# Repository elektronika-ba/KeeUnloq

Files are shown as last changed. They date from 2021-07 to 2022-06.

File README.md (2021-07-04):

# KeeUnloq
Tool for playing with Microchip KeeLoq technology.

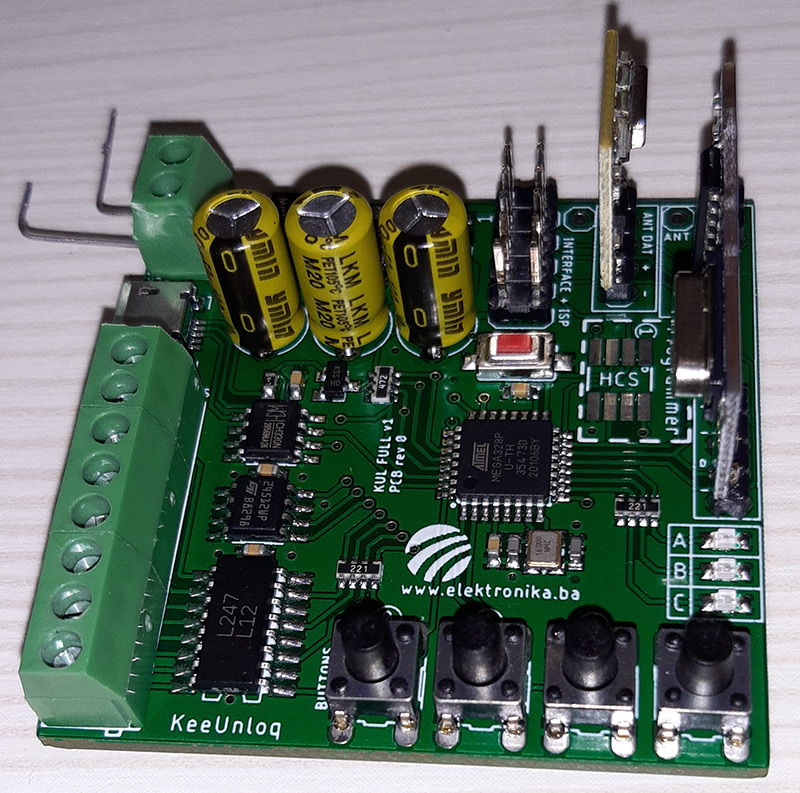
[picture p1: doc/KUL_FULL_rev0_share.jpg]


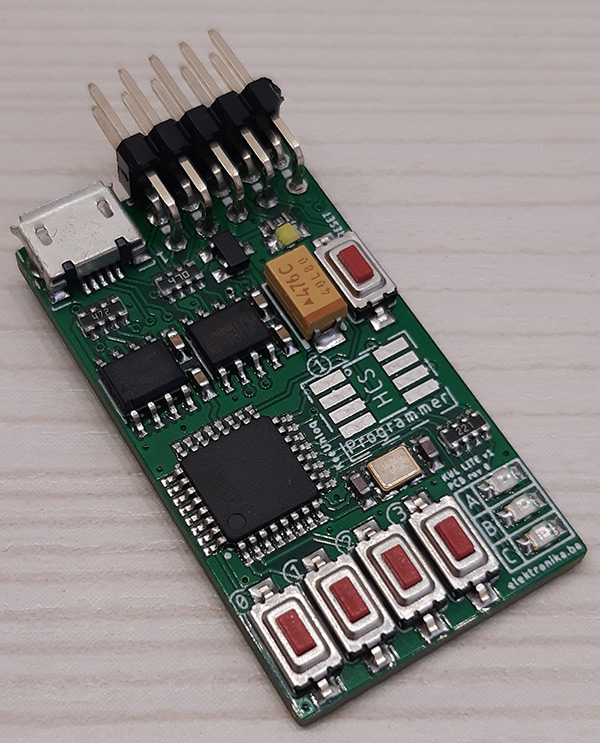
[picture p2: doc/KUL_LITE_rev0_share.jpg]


# Status
Under development. More information will be available on www.elektronika.ba

Read the doc @ [Documentation](doc/KeeUnloq_fw1.0.docx)

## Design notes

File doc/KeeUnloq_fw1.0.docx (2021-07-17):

# KeeUnloq

Open-source tools for exploring Microchip KeeLoq keyless remote systems (the old ones).

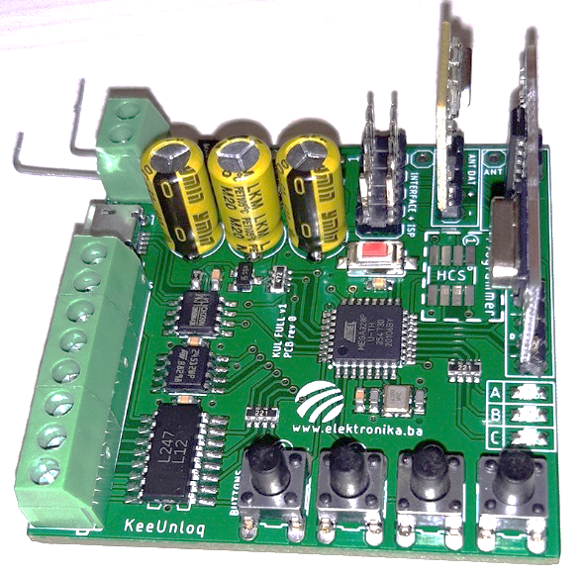
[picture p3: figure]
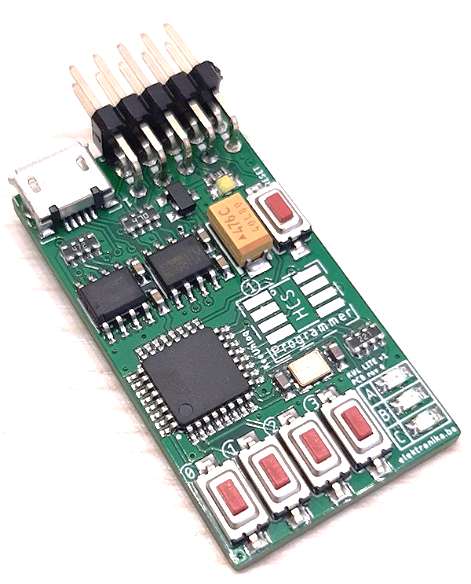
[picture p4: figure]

KUL FULL v1 PCB rev 0 | KUL LITE v1 PCB rev 0

## Features

Device comes in two PCB variants: KUL FULL and KUL LITE.

Note: version KUL FULL contains RF receiver and transmitter while KUL LITE does not.

- Receiver module with optocouplers (only with PCB „KUL FULL“)
- Upgrading third-party insecure systems that use fixed-code HCS101 with rolling-code HCS versions (HCS200, HCS300, ...)
- Emulating HCS transmitter (only with PCB „KUL FULL“ or with external RF ASK transmitter)
- KeeLoq HCS series programmer tool (requires PC software)
- PC software for programming HCS series chips, upload & download of collected transmitter data and more
- Firmware upgrade via USB
- Powered externally or by USB
  - 5V DC or 9-24 AC/DC (PCB „KUL FULL“)
  - 5V DC (PCB „KUL LITE“)
- Open source

## Modes of operation/options

Devices with FW v1 supports four selectable options during its operation:

1. Option 1: Receiver module with memory of up to 1000 remote transmitters
2. Option 2: MITM upgrader for upgrading third-party systems (insecure garage door openers)
3. Option 3: Data collector with memory of up to 200 remote transmitters and 500 transmissions
4. Option 4: Transmitter emulator

### Setting options

Each option can be enabled/disabled by holding down button S0 and resetting the device (via reset button or by supplying power). In this state LED A will remain ON and device will report status of all options (enabled/disabled). Option can be selected with button S1 and switching its state is done with button S2. When option is selected with button S1 its current state (enabled/disabled) is shown on LED C (blinking 1 time = disabled, blinking 2 times = enabled).

Example 1: LED B blinks 2 times, and LED C blinks 2 times: Option 2 is enabled.

Example 2: LED B blinks 3 times, and LED C blinks 1 time: Option 3 is disabled.

If buttons S1 or S2 are not pressed within 15 seconds, the device will exit option-change procedure and start with operation with currently enabled options. If you need exit the procedure before the timeout, press button S3.

Upon startup the device will always report the state of all options on LED A.

Example: If options 1 and 3 are enabled, LED A will blink as: 1 time – pause – 3 times.

Note: When Option 4 is enabled, it will automatically disable all other options.

### Option 1: Receiver module

Receiver module is used as a stand-alone receiver, which is capable of learning up to 1000 KeeLoq remote transmitters. It has 4 digital optocoupler outputs S0-S3 (only PCB „KUL FULL“) which are usually connected to garage door and parking barrier motor controllers. It is also capable of learning fixed-code and rolling-code HCS series that require programming before usage.

Please refer to Table 1 in Programming remote transmitters and encoder ICs.

### Option 2: MITM upgrader

Man-in-the-middle upgrader is a mode of operation where the goal is to upgrade a fixed-code insecure third-party system with a rolling-code transmitter. Rolling-code HCS series are pin-compatible with HCS101 fixed code encoder so modifying existing insecure transmitters should be an easy task by simply replacing ICs and programming new HCS with KeeUnloq device.

In order for this mode of operation to be successful, a third-party system must be modified as shown in the schematic diagram below.

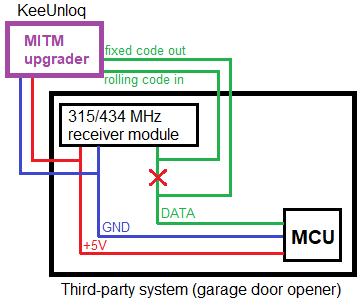
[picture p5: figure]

The data line of the third-party system must be intercepted so that any data received by the RF receiver is passed into the KeeUnloq device, and special data line from the KeeUnloq device passed into the third-party system.

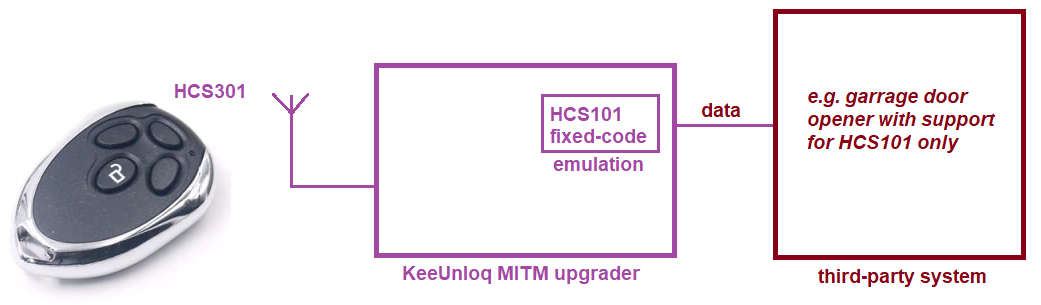
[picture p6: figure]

This means that KeeUnloq device must learn:

1. Fixed-code HCS101 remote control (only one HCS101) that third-party system already recognizes and works with
2. Rolling-code transmitter that will be learned by the KeeUnloq device (as many as required)

After installing the KeeUnloq MITM device into the third-party system, regular programming must take place with one exception: ~~The remote transmitter that has been last learned by the~~ ~~KeeUnloq~~ ~~device will be passed/proxied into the third-party system upon reception of a valid learned rolling-code remote transmitter.~~

Please refer to Table 1 in Programming remote transmitters and encoder ICs.

### Option 3: Data collector

This option is intended for collecting KeeLoq data from the air in order to evaluate and study the security of third-party systems for vulnerabilities.

When device is in this state it will listen and collect transmissions into internal EEPROM memory. All data can be downloaded to PC software via USB connection for later analysis.

Pressing button S0 on device will indicate how many new remote devices have been collected until device has started/booted.

Pressing button S1 on device will indicate how many devices are collected in entire EEPROM memory.

Number of collected transmitters is reported by blinking the LEDs:

- LED A – hundreds
- LED B – tens
- LED C – ones

Example 1: LED A blinks 2 times, LED B does not blink, LED C blinks 7 times; the resulting number is 207.

Example 2: LED A blinks 11 times, LED B blinks 2 times, LED C does not blink; the resulting number is 1120.

### Option 4: Transmitter emulator

In this mode it is possible to emulate any of the HCS series encoders. It is required to previously program the “transmitter identity” via USB connection and PC software:

1. Type of encoder (HCS*)
2. Serial number
3. Encryption key (if applicable)
4. Counter value

Once device is in this mode, all four buttons are used to transmit the data (S0 – S3).

## Programming remote transmitters and encoder ICs

Programming is done by accessing buttons S0-S3 or via PC software when device is connected via USB.

Program & learn

To learn rolling-code encoder into the device memory, place programming clips on the HCS IC or place it on the PCB programming slot and hold it down firmly. Hold button S0 to enter programming mode and LED B will turn ON. Within 20 seconds press one of the buttons:

- S0 – program&enroll 66 bit encoder (HCS200)
- S1 – program&enroll 66 bit encoder (HCS201)
- S2 – program&enroll 66 bit encoder (HCS300, HCS301, HCS320)
- S3 – program&enroll 67 bit encoder (HCS360, HCS361)

Each HCS encoder IC will be programmed with a random serial number, random encryption key, random discrimination value (except HCS360 & HCS361 which mirror the serial number value) and random counter value (but kept in the range of 0 – 255). This means that encoder ICs programmed using KeeUnloq device cannot be later enrolled using “Learn from RF” function in case KeeUnloq memory is later deleted - encoder ICs will need to be re-programmed. If it is required that all encoder ICs share the same encryption key, then use the PC tool to program them individually to the master encryption key of your choice. This master key resides in KeeUnloq memory.

The device will remain in this state for 20 seconds after the last transmitter has been programmed and will exit automatically.

Learn from RF

To learn a remote transmitter into the device memory from RF, hold button S1 to enter programming mode and LED B will turn ON. Within 10 seconds press any button on a remote control and LED B will start blinking. Press again the same button on remote control within 5 seconds.

If learning process was successful LED C will blink:

- 2 times if remote has been recognized using pre-configured master key as a rolling-code encoder
- 5 times if remote has been recognized as a fixed-code encoder or if using the pre-configured master key did not decrypt the data successfully so the encoder received will be treated as fixed-code type

If programming was not successful LED A will blink:

- 2 times if remote is already programmed into the memory (you can try first deleting it and then learning it again)
- 3 times if device is in Mode 2 and there is already HCS101 emulating encoder enrolled
- 5 times if remote failed to program because second reception did not match the first reception (you can simply try again)
- 10 times if this remote is not supported by current firmware

The device will remain in this state for 10 seconds after the last transmitter has been received and will exit automatically.

This process will enroll a fixed-code remote transmitter HCS101 any time, or a rolling-code transmitter with the encryption key that has been earlier loaded into the KeeUnloq device via USB and PC configuration tool. This also means that every remote transmitter must have this exact encryption key already programmed into them. It will also enroll a rolling-code transmitter even if the encryption key does not match, however it will be treated as a fixed-code transmitter where only serial number is used just like with HCS101.
Remove transmitter from memory (one-by-one) | In order to delete a specific remote transmitter from the memory, press and hold button S2. LED B will start blinking. Press any button on a remote transmitter that needs to be deleted from the memory. LED A will turn ON to indicate the successful reception of the code. When remote transmitter has been deleted from the memory, LED C will blink 2 times to confirm deletion, or LED A will blink 2 times to confirm that remote has not been found in memory. The device will remain in this state for 10 seconds after the last transmitter has been received and will exit automatically.
Clear all memory | In order to clear all memory from the device, press and hold button S3 until LED A starts blinking. Now within 5 seconds press and hold button S2 until LEDs B&C turn on. Release all buttons and wait until all LEDs finally turn off – the memory is clear. When options are enabled: - Option 1: will delete learned/enrolled encoders that can operate the device - Option 2: will delete learned/enrolled MITM emulating encoder - Option 3: will delete entire grabbed/log table - Option 4: will delete nothing

Table 1: programming remote transmitters and encoder ICs

## Appendix

Example of installation of MITM Upgrader into a garage door opener that supports HCS101. Before continuing make sure that garage door opener is programmed and controllable by the working remote transmitter that has HCS101 encoder inside.

Step 1: access the garage door openers RF receiver

Step 2: cut the data line and pass it through the KeeUnloq device and power up the garage door opener. Now change KeeUnloq mode into the MITM Upgrader (refer to the instructions in this document on how to change the operating mode)

Step 3: perform the Program & learn procedure of the existing HCS101 remote controller into the KeeUnloq

Step 4: order new remote transmitters with rolling-code HCS encoder IC (such as: HCS200, HCS300, …) or remove existing HCS101 encoder IC from your current remote controller

Step 5: perform the Program & learn procedure of the new HCS encoder IC by using the programming clips or by using the pads on KeeUnloq device (in case you haven’t already soldered new HCS encoder IC onto the remote transmitter)

Step 6: test for proper operation of garage door opener with KeeUnloq device and your new rolling-code transmitter

Elektronika-ba, draft 2021-7-4

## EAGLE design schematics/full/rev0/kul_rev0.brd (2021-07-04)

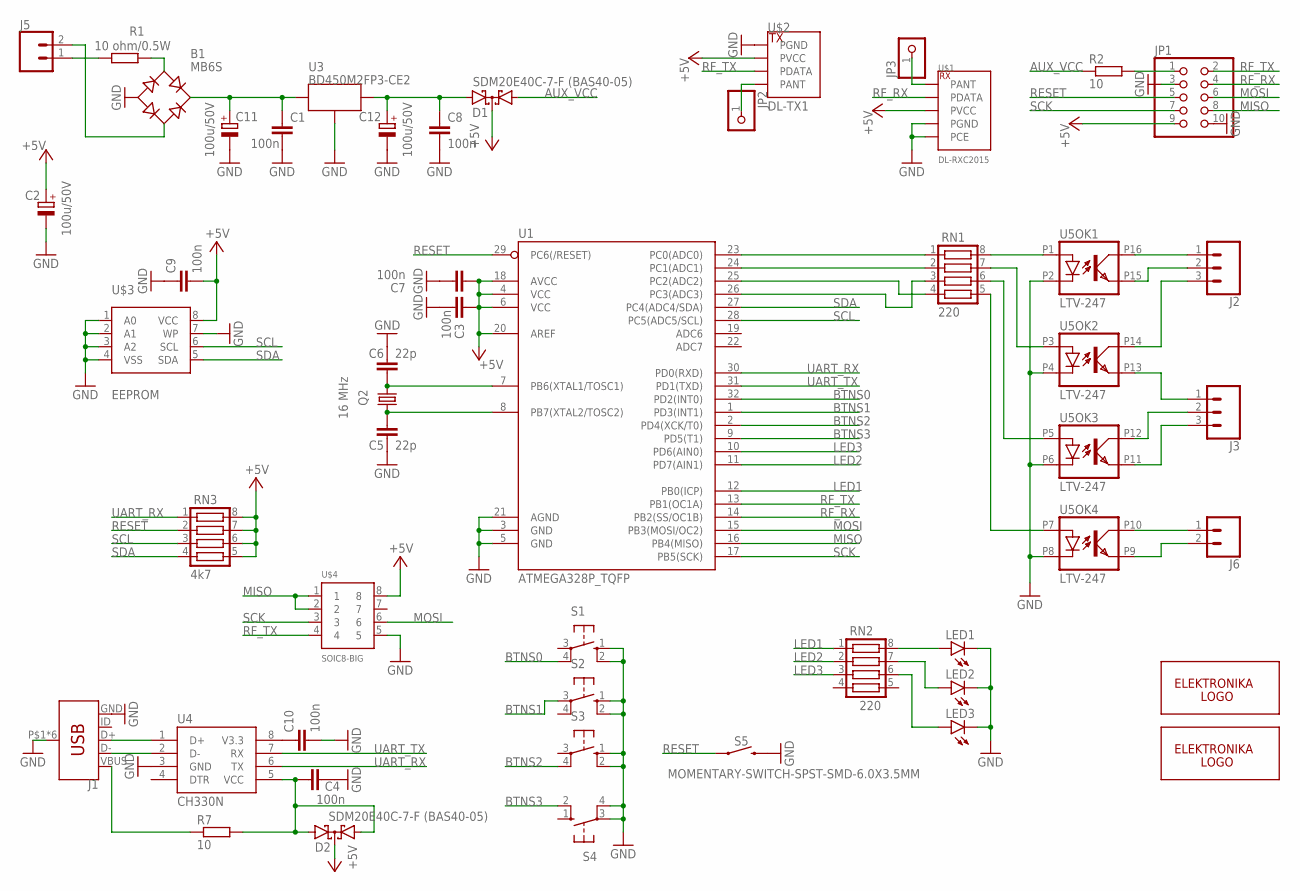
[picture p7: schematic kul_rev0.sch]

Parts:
B1: MB6S; SOIC-4
C1, C3, C4, C7, C8, C9, C10: 100n; C0603
C2, C11, C12: 100u/50V; E5-6
C5, C6: 22p; C0603
D1, D2: SDM20E40C-7-F (BAS40-05); SOT23
J1: USB_MICRO-BLCSC; C40951_USB
J2, J3: CONN_03SCREW_LOCK; SCREWTERMINAL-3.5MM-3_LOCK.007S
J5, J6: CONN_023.5MM; SCREWTERMINAL-3.5MM-2
JP1: PINHD-2X5; 2X05
JP2, JP3: PINHD-1X1; 1X01
LED1, LED2, LED3: LEDCHIP-LED0805; CHIP-LED0805
Q2: 16 MHz; 3.2X2.5_KX-7
R1: 10 ohm/0.5W; R0805
R2, R7: 10; R0603
RN1, RN2: 220; CTS742C083
RN3: 4k7; CTS742C083
S1, S2, S3, S4: 10-XX; B3F-10XX
S5: MOMENTARY-SWITCH-SPST-SMD-6.0X3.5MM; TACTILE_SWITCH_SMD_6.0X3.5MM
U1: ATMEGA328P_TQFP; TQFP32-08
U3: BD450M2FP3-CE2; C308597_LDO
U4: CH330N; SOIC8
U5: LTV-247; SOP-16_4.4MM
U$1: DL-RXC2015
U$2: DL-TX1
U$3: EEPROM; SOIC8
U$4: SOIC8-BIG; SOIC8_BIG
U$5: ELEKTRONIKA_BA_ELEBA_LOGO-121; ELEKTRONIKA_BA_ELEBALOGO_ELEBALOGO_B_121
U$6: ELEKTRONIKA_BA_ELEBA_LOGO; ELEKTRONIKA_BA_ELEBALOGO_ELEBALOGO_B_122

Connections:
+5V: C2.+, C3.2, C7.2, C9.2, D1.3 (C), D2.3 (C), JP1.9, RN3.5, RN3.6, RN3.7, RN3.8, U1.4 (VCC), U1.6 (VCC), U1.18 (AVCC), U1.20 (AREF), U$1.PVCC, U$2.PVDD (PVCC), U$3.8 (VCC), U$4.8
AUX_VCC: D1.1 (A1), R2.1
BTNS0: S1.4 (P1), U1.32 (PD2(INT0))
BTNS1: S2.3, U1.1 (PD3(INT1))
BTNS2: S3.4 (P1), U1.2 (PD4(XCK/T0))
BTNS3: S4.2 (S1), U1.9 (PD5(T1))
GND: B1.-, C1.2, C2.-, C3.1, C4.2, C5.2, C6.1, C7.1, C8.2, C9.1, C10.2, C11.-, C12.-, J1.GND, J1.P$1 (SHIELD), J1.P$2 (SHIELD), J1.P$3 (SHIELD), J1.P$4 (SHIELD), J1.SHIELD1 (SHIELD), J1.SHIELD2 (SHIELD), JP1.3, JP1.10, LED1.C, LED2.C, LED3.C, S1.1 (S), S1.2 (S1), S2.1 (S), S2.2 (S1), S3.1 (S), S3.2 (S1), S4.3, S4.4 (P1), S5.2, U1.3 (GND), U1.5 (GND), U1.21 (AGND), U3.PGND1 (PGND), U3.PGND2 (PGND), U4.3 (GND), U5.P2 (C), U5.P4 (C), U5.P6 (C), U5.P8 (C), U$1.PCE, U$1.PGND1 (PGND), U$1.PGND2 (PGND), U$2.PGND, U$3.1 (A0), U$3.2 (A1), U$3.3 (A2), U$3.4 (VSS), U$3.7 (WP), U$4.5
LED1: RN2.1, U1.12 (PB0(ICP))
LED2: RN2.2, U1.11 (PD7(AIN1))
LED3: RN2.3, U1.10 (PD6(AIN0))
MISO: JP1.8, U1.16 (PB4(MISO)), U$4.1, U$4.2
MOSI: JP1.6, U1.15 (PB3(MOSI/OC2)), U$4.6
unnamed: RN1.8, U5.P1 (A)
unnamed: RN1.7, U5.P3 (A)
unnamed: RN1.6, U5.P5 (A)
unnamed: RN1.5, U5.P7 (A)
unnamed: RN1.4, U1.25 (PC2(ADC2))
unnamed: RN1.3, U1.26 (PC3(ADC3))
unnamed: J1.D+, U4.1 (D+)
unnamed: B1.~1 (AC1), R1.1
unnamed: B1.~2 (AC2), J5.2
unnamed: B1.+, C1.1, C11.+, U3.PIN
unnamed: C8.1, C12.+, D1.2 (A2), U3.POUT
unnamed: J5.1, R1.2
unnamed: J1.D-, U4.2 (D-)
unnamed: J1.VBUS, R7.1
unnamed: C4.1, D2.1 (A1), D2.2 (A2), R7.2, U4.5 (VCC)
unnamed: C10.1, U4.8 (V3.3)
unnamed: J2.1, U5.P16 (COL)
unnamed: J2.2, U5.P15 (EMIT)
unnamed: J2.3, U5.P14 (COL)
unnamed: J3.1, U5.P13 (EMIT)
unnamed: J3.2, U5.P12 (COL)
unnamed: J3.3, U5.P11 (EMIT)
unnamed: J6.1, U5.P10 (COL)
unnamed: J6.2, U5.P9 (EMIT)
unnamed: RN1.1, U1.23 (PC0(ADC0))
unnamed: RN1.2, U1.24 (PC1(ADC1))
unnamed: JP2.1, U$2.PANT
unnamed: JP3.1, U$1.PANT
unnamed: LED1.A, RN2.8
unnamed: LED2.A, RN2.7
unnamed: LED3.A, RN2.6
unnamed: JP1.1, R2.2
OSC1: C6.2, Q2.3 (2), U1.7 (PB6(XTAL1/TOSC1))
OSC2: C5.1, Q2.1, U1.8 (PB7(XTAL2/TOSC2))
RESET: JP1.5, RN3.2, S5.1, U1.29 (PC6(/RESET))
RF_RX: JP1.4, U1.14 (PB2(SS/OC1B)), U$1.PDATA
RF_TX: JP1.2, U1.13 (PB1(OC1A)), U$2.PDATA, U$4.4
SCK: JP1.7, U1.17 (PB5(SCK)), U$4.3
SCL: RN3.3, U1.28 (PC5(ADC5/SCL)), U$3.6 (SCL)
SDA: RN3.4, U1.27 (PC4(ADC4/SDA)), U$3.5 (SDA)
UART_RX: RN3.1, U1.30 (PD0(RXD)), U4.6 (TX)
UART_TX: U1.31 (PD1(TXD)), U4.7 (RX)

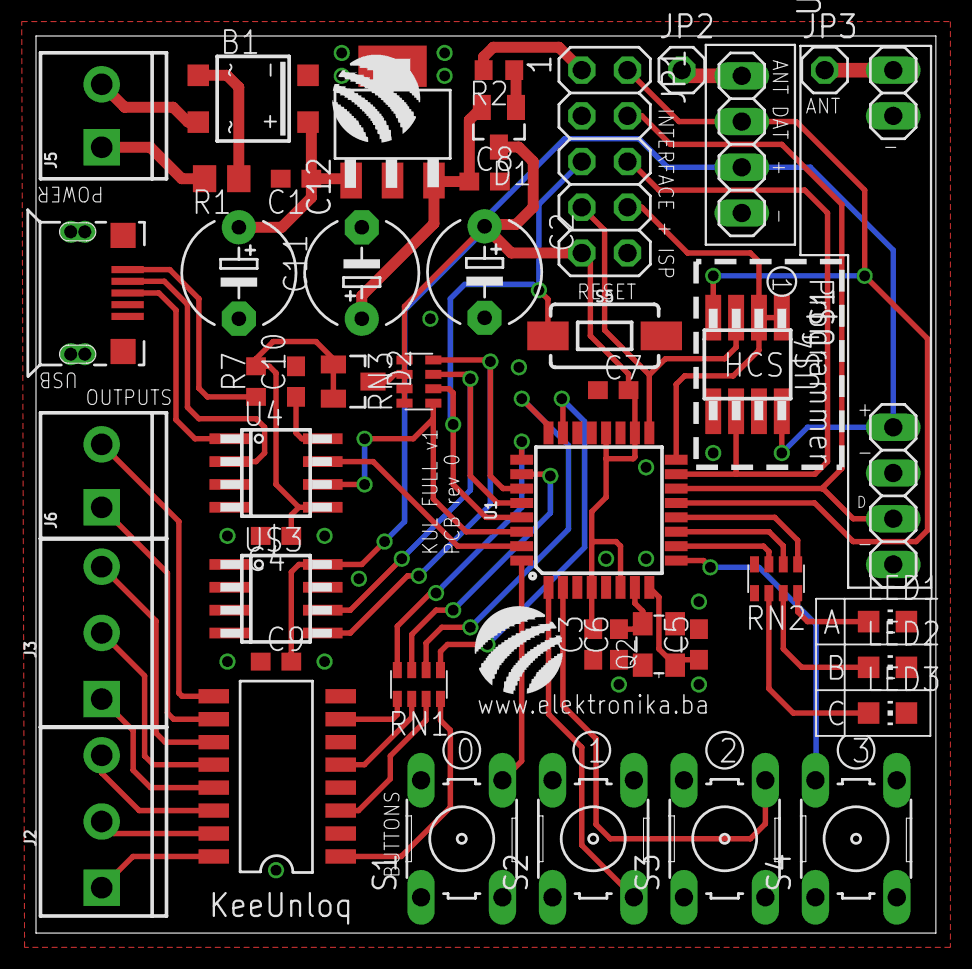
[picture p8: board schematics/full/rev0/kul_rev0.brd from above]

Board: 2 copper layers, 50.0 x 49.8 mm, 48 parts (1 on the bottom side), 54 nets.

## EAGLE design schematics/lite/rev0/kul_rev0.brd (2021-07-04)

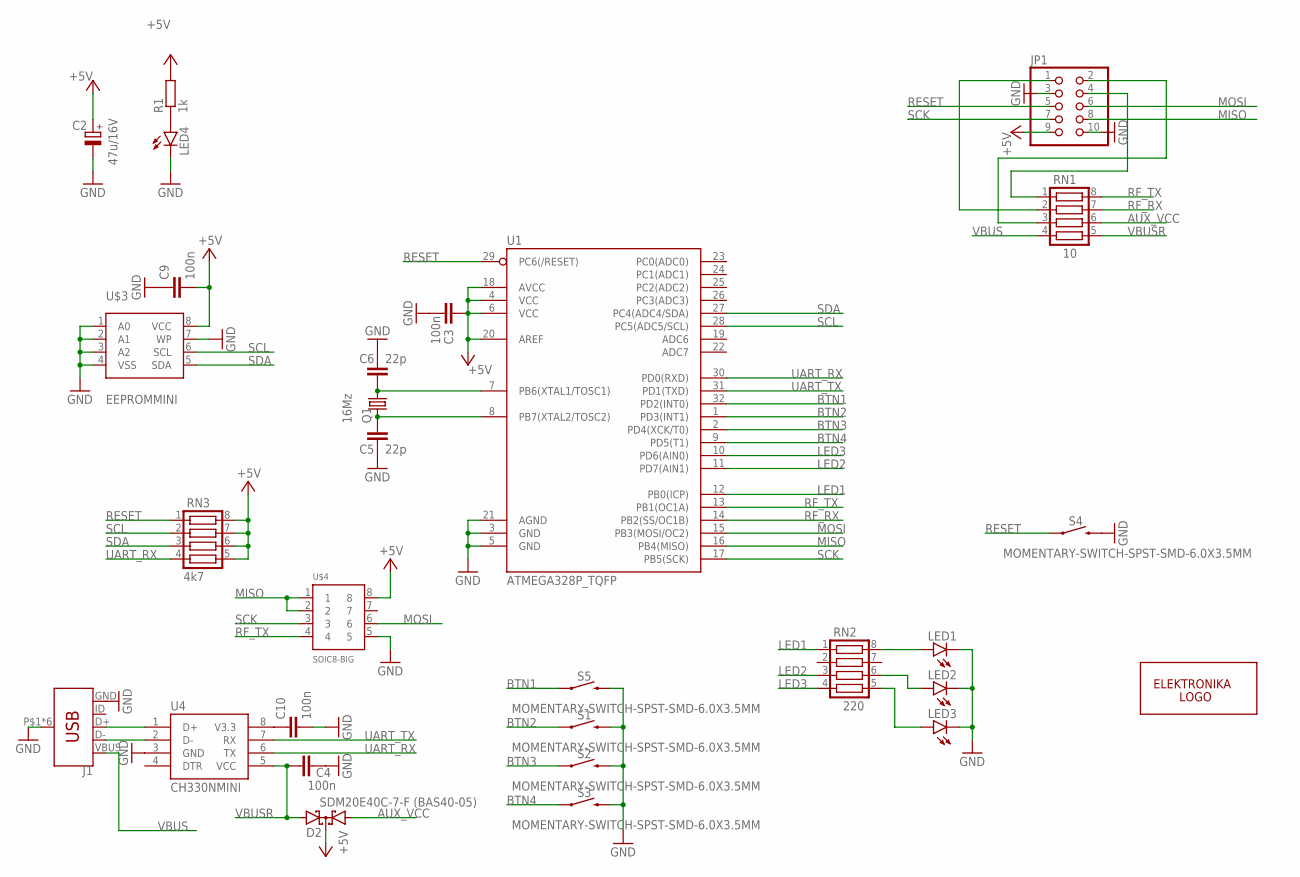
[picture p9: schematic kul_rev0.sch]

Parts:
C2: 47u/16V; CT6032
C3, C4, C9, C10: 100n; C0603
C5, C6: 22p; C0603
D2: SDM20E40C-7-F (BAS40-05); SOT23
J1: USB_MICRO-BLCSC; C40951_USB
JP1: PINHD-2X5/90; 2X05/90
LED1, LED2, LED3, LED4: LEDCHIP-LED0805; CHIP-LED0805
Q1: 16Mz; 3.2X2.5_KX-7
R1: 1k; R0603
RN1: 10; CTS742C083
RN2: 220; CTS742C083
RN3: 4k7; CTS742C083
S1, S2, S3, S4, S5: MOMENTARY-SWITCH-SPST-SMD-6.0X3.5MM; TACTILE_SWITCH_SMD_6.0X3.5MM
U1: ATMEGA328P_TQFP; TQFP32-08
U4: CH330NMINI; SOIC8_MINI
U$3: EEPROMMINI; SOIC8_MINI
U$4: SOIC8-BIG; SOIC8_BIG
U$6: ELEKTRONIKA_BA_ELEBA_LOGO; ELEKTRONIKA_BA_ELEBALOGO_ELEBALOGO_B_122

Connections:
+5V: C2.+, C3.2, C9.2, D2.3 (C), JP1.9, R1.2, RN3.5, RN3.6, RN3.7, RN3.8, U1.4 (VCC), U1.6 (VCC), U1.18 (AVCC), U1.20 (AREF), U$3.8 (VCC), U$4.8
AUX_VCC: D2.1 (A1), RN1.6
BTN1: S5.1, U1.32 (PD2(INT0))
BTN2: S1.1, U1.1 (PD3(INT1))
BTN3: S2.1, U1.2 (PD4(XCK/T0))
BTN4: S3.1, U1.9 (PD5(T1))
GND: C2.-, C3.1, C4.2, C5.2, C6.1, C9.1, C10.2, J1.GND, J1.P$1 (SHIELD), J1.P$2 (SHIELD), J1.P$3 (SHIELD), J1.P$4 (SHIELD), J1.SHIELD1 (SHIELD), J1.SHIELD2 (SHIELD), JP1.3, JP1.10, LED1.C, LED2.C, LED3.C, LED4.C, S1.2, S2.2, S3.2, S4.2, S5.2, U1.3 (GND), U1.5 (GND), U1.21 (AGND), U4.3 (GND), U$3.1 (A0), U$3.2 (A1), U$3.3 (A2), U$3.4 (VSS), U$3.7 (WP), U$4.5
LED1: RN2.1, U1.12 (PB0(ICP))
LED2: RN2.3, U1.11 (PD7(AIN1))
LED3: RN2.4, U1.10 (PD6(AIN0))
MISO: JP1.8, U1.16 (PB4(MISO)), U$4.1, U$4.2
MOSI: JP1.6, U1.15 (PB3(MOSI/OC2)), U$4.6
unnamed: JP1.2, RN1.3
unnamed: JP1.4, RN1.1
unnamed: LED2.A, RN2.6
unnamed: LED1.A, RN2.8
unnamed: LED4.A, R1.1
unnamed: J1.D+, U4.1 (D+)
unnamed: J1.D-, U4.2 (D-)
unnamed: C10.1, U4.8 (V3.3)
unnamed: LED3.A, RN2.5
unnamed: JP1.1, RN1.2
OSC1: C6.2, Q1.3 (2), U1.7 (PB6(XTAL1/TOSC1))
OSC2: C5.1, Q1.1, U1.8 (PB7(XTAL2/TOSC2))
RESET: JP1.5, RN3.1, S4.1, U1.29 (PC6(/RESET))
RF_RX: RN1.7, U1.14 (PB2(SS/OC1B))
RF_TX: RN1.8, U1.13 (PB1(OC1A)), U$4.4
SCK: JP1.7, U1.17 (PB5(SCK)), U$4.3
SCL: RN3.2, U1.28 (PC5(ADC5/SCL)), U$3.6 (SCL)
SDA: RN3.3, U1.27 (PC4(ADC4/SDA)), U$3.5 (SDA)
UART_RX: RN3.4, U1.30 (PD0(RXD)), U4.6 (TX)
UART_TX: U1.31 (PD1(TXD)), U4.7 (RX)
VBUS: J1.VBUS, RN1.4
VBUSR: C4.1, D2.2 (A2), RN1.5, U4.5 (VCC)

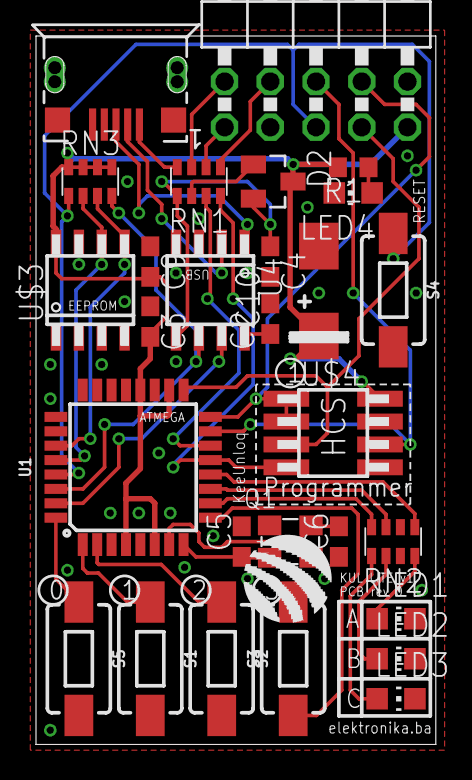
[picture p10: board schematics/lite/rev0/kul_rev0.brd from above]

Board: 2 copper layers, 22.2 x 39.4 mm, 29 parts (1 on the bottom side), 34 nets.

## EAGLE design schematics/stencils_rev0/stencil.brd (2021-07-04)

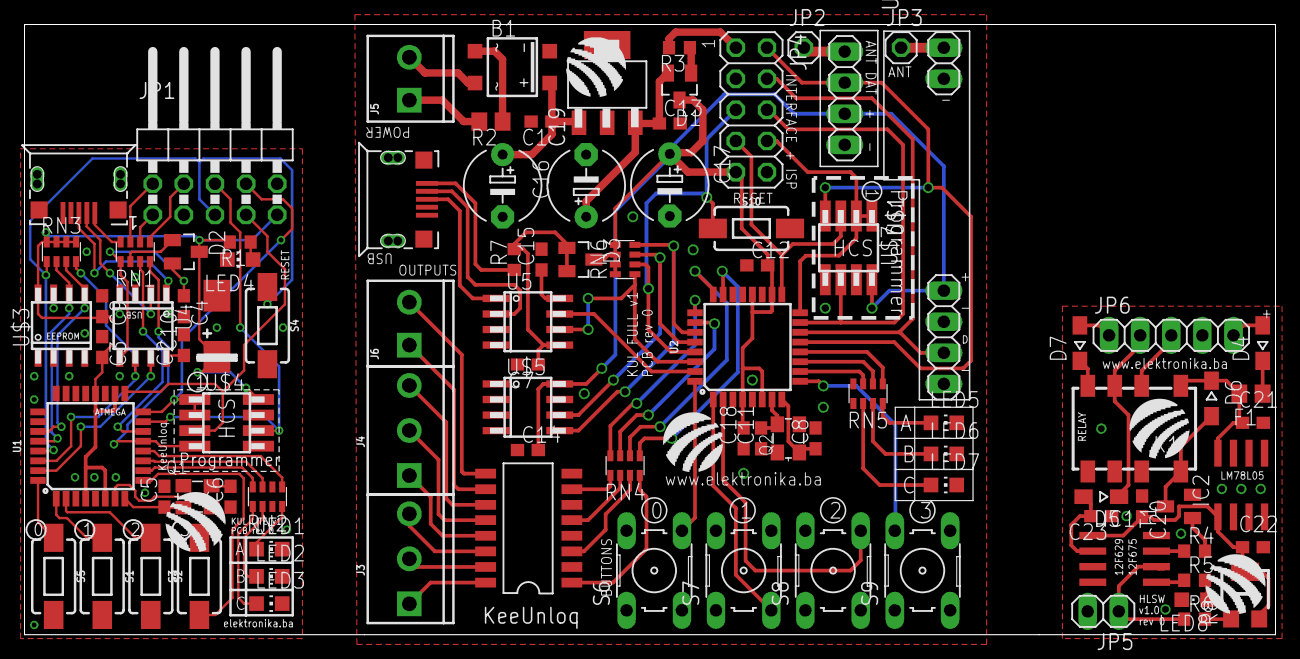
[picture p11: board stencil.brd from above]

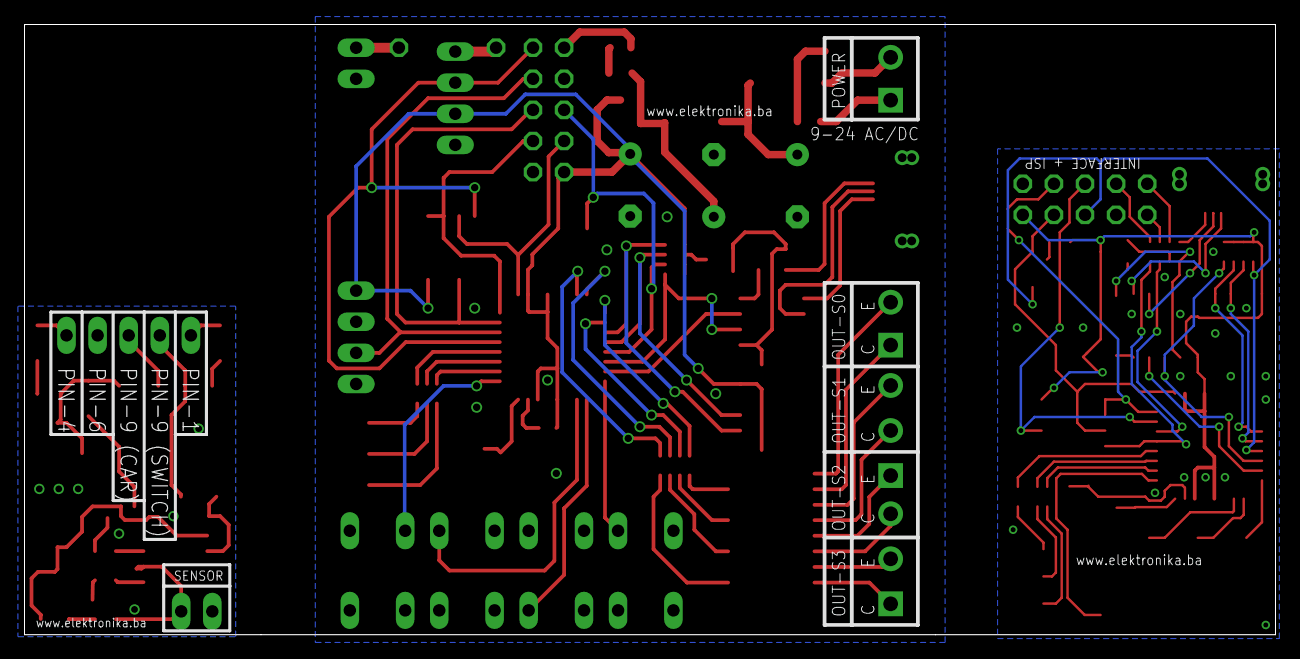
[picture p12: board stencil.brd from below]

Board: 2 copper layers, 102.2 x 49.8 mm, 99 parts (3 on the bottom side), 105 nets.

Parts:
B1: MB6S; SOIC-4
C1, C3, C4, C7, C9, C10, C12, C13, C14, C15, C18, C20, C23: 100n; C0603
C2: 47u/16V; CT6032
C5, C6, C8, C11: 22p; C0603
C16, C17, C19: 100u/50V; E5-6
C21: 470n; C0603
C22: 330n; C0603
D1, D2, D3: SDM20E40C-7-F (BAS40-05); SOT23
D4, D5, D6, D7: 1N4148; SOD323-W
F1: PTC 0.1A 15V; R0805
IC1: PIC12F675SN; SO-08
IC2: 78L05SMD; SO08
J1, J2: C40951_USB
J3, J4: SCREWTERMINAL-3.5MM-3_LOCK.007S
J5, J6: SCREWTERMINAL-3.5MM-2
JP1: 2X05/90
JP2, JP3: 1X01
JP4: 2X05
JP5: 1X02
JP6: 1X05
K1: G6K-2F-Y
LED1, LED2, LED3, LED4, LED5, LED6, LED7: CHIP-LED0805
LED8: RED; CHIPLED_0805
Q1: 16Mz; 3.2X2.5_KX-7
Q2: 16 MHz; 3.2X2.5_KX-7
R1, R5, R6: 1k; R0603
R2: 22; R0805
R3, R7: 10; R0603
R4: 2k2; R0603
R8: 15k; RTRIMCVR42A
RN1: 10; CTS742C083
RN2, RN4, RN5: 220; CTS742C083
RN3, RN6: 4k7; CTS742C083
S1, S2, S3, S4, S5, S10: MOMENTARY-SWITCH-SPST-SMD-6.0X3.5MM; TACTILE_SWITCH_SMD_6.0X3.5MM
S6, S7, S8, S9: B3F-10XX
T1: BC546; SOT23-BEC
U1, U2: ATMEGA328P_TQFP; TQFP32-08
U3: BD450M2FP3-CE2; C308597_LDO
U4: CH330NMINI; SOIC8_MINI
U5: CH330N; SOIC8
U6: LTV-247; SOP-16_4.4MM
U$1: DL-RXC2015
U$2: DL-TX1
U$3: EEPROMMINI; SOIC8_MINI
U$4, U$7: SOIC8-BIG; SOIC8_BIG
U$5: EEPROM; SOIC8
U$6, U$9, U$10: ELEKTRONIKA_BA_ELEBA_LOGO; ELEKTRONIKA_BA_ELEBALOGO_ELEBALOGO_B_122
U$8, U$11: ELEKTRONIKA_BA_ELEBA_LOGO-121; ELEKTRONIKA_BA_ELEBALOGO_ELEBALOGO_B_121

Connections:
1-PIN: D7.A, JP6.1
4-PIN: D4.A, JP6.5
9-CAR: JP6.3, K1.2
9-HLSW: D5.C, JP6.2, K1.3
!ENAB: C23.2, D5.A, IC1.2
+5V: C2.+, C3.2, C9.2, D2.3, JP1.9, R1.2, RN3.5, RN3.6, RN3.7, RN3.8, U1.4, U1.6, U1.18, U1.20, U$3.8, U$4.8
+5V1: C12.2, C14.2, C17.+, C18.2, D1.3, D3.3, JP4.9, RN6.5, RN6.6, RN6.7, RN6.8, U2.4, U2.6, U2.18, U2.20, U$1.PVCC, U$2.PVDD, U$5.8, U$7.8
+5V2: C20.2, C22.1, IC1.1, IC2.1, R8.2, R8.3
+12V: C21.1, D6.C, F1.2, IC2.8, K1.1
AUX_VCC: D2.1, RN1.6
AUX_VCC1: D1.1, R3.1
BTN1: S5.1, U1.32
BTN2: S1.1, U1.1
BTN3: S2.1, U1.2
BTN4: S3.1, U1.9
BTN5: S6.4, U2.32
BTN6: S7.3, U2.1
BTN7: S8.4, U2.2
BTN8: S9.2, U2.9
GND: C2.-, C3.1, C4.2, C5.2, C6.1, C9.1, C10.2, J1.GND, J1.P$1, J1.P$2, J1.P$3, J1.P$4, J1.SHIELD1, J1.SHIELD2, JP1.3, JP1.10, LED1.C, LED2.C, LED3.C, LED4.C, S1.2, S2.2, S3.2, S4.2, S5.2, U1.3, U1.5, U1.21, U4.3, U$3.1, U$3.2, U$3.3, U$3.4, U$3.7, U$4.5
GND1: B1.-, C1.2, C7.2, C8.2, C11.1, C12.1, C13.2, C14.1, C15.2, C16.-, C17.-, C18.1, C19.-, J2.GND, J2.P$1, J2.P$2, J2.P$3, J2.P$4, J2.SHIELD1, J2.SHIELD2, JP4.3, JP4.10, LED5.C, LED6.C, LED7.C, S6.1, S6.2, S7.1, S7.2, S8.1, S8.2, S9.3, S9.4, S10.2, U2.3, U2.5, U2.21, U3.PGND1, U3.PGND2, U5.3, U6.P2, U6.P4, U6.P6, U6.P8, U$1.PCE, U$1.PGND1, U$1.PGND2, U$2.PGND, U$5.1, U$5.2, U$5.3, U$5.4, U$5.7, U$7.5
GND2: C20.1, C21.2, C22.2, C23.1, IC1.8, IC2.2, IC2.3, IC2.6, IC2.7, JP5.2, JP6.4, LED8.C, T1.E
LED1: RN2.1, U1.12
LED2: RN2.3, U1.11
LED3: RN2.4, U1.10
LED4: RN5.1, U2.12
LED5: RN5.2, U2.11
LED6: RN5.3, U2.10
MISO: JP1.8, U1.16, U$4.1, U$4.2
MISO1: JP4.8, U2.16, U$7.1, U$7.2
MOSI: JP1.6, U1.15, U$4.6
MOSI1: JP4.6, U2.15, U$7.6
unnamed: JP1.2, RN1.3
unnamed: JP1.4, RN1.1
unnamed: LED2.A, RN2.6
unnamed: LED1.A, RN2.8
unnamed: LED4.A, R1.1
unnamed: RN4.8, U6.P1
unnamed: RN4.7, U6.P3
unnamed: J1.D+, U4.1
unnamed: RN4.6, U6.P5
unnamed: RN4.5, U6.P7
unnamed: B1.~1, R2.1
unnamed: B1.~2, J5.2
unnamed: B1.+, C1.1, C16.+, U3.PIN
unnamed: J1.D-, U4.2
unnamed: C13.1, C19.+, D1.2, U3.POUT
unnamed: J2.D+, U5.1
unnamed: C10.1, U4.8
unnamed: J2.D-, U5.2
unnamed: J2.VBUS, R7.1
unnamed: C7.1, D3.1, D3.2, R7.2, U5.5
unnamed: C15.1, U5.8
unnamed: J3.1, U6.P16
unnamed: J3.2, U6.P15
unnamed: J3.3, U6.P14
unnamed: J4.1, U6.P13
unnamed: J4.2, U6.P12
unnamed: J4.3, U6.P11
unnamed: J6.1, U6.P10
unnamed: J6.2, U6.P9
unnamed: RN4.1, U2.23
unnamed: RN4.2, U2.24
unnamed: JP2.1, U$2.PANT
unnamed: JP3.1, U$1.PANT
unnamed: LED3.A, RN2.5
unnamed: JP1.1, RN1.2
unnamed: LED5.A, RN5.8
unnamed: LED6.A, RN5.7
unnamed: LED7.A, RN5.6
unnamed: J5.1, R2.2
unnamed: JP4.1, R3.2
unnamed: RN4.4, U2.25
unnamed: RN4.3, U2.26
unnamed: D4.C, F1.1
unnamed: LED8.A, R5.2
unnamed: IC1.6, JP5.1, R6.1
unnamed: IC1.5, R5.1
unnamed: R4.2, T1.B
unnamed: IC1.7, R4.1
unnamed: D6.A, K1.8, T1.C
unnamed: D7.C, K1.4
unnamed: R6.2, R8.1
OSC1: C6.2, Q1.3, U1.7
OSC2: C5.1, Q1.1, U1.8
OSC3: C11.2, Q2.3, U2.7
OSC4: C8.1, Q2.1, U2.8
RESET: JP1.5, RN3.1, S4.1, U1.29
RESET1: JP4.5, RN6.2, S10.1, U2.29
RF_RX: RN1.7, U1.14
RF_RX1: JP4.4, U2.14, U$1.PDATA
RF_TX: RN1.8, U1.13, U$4.4
RF_TX1: JP4.2, U2.13, U$2.PDATA, U$7.4
SCK: JP1.7, U1.17, U$4.3
SCK1: JP4.7, U2.17, U$7.3
SCL: RN3.2, U1.28, U$3.6
SCL1: RN6.3, U2.28, U$5.6
SDA: RN3.3, U1.27, U$3.5
SDA1: RN6.4, U2.27, U$5.5
UART_RX: RN3.4, U1.30, U4.6
UART_RX1: RN6.1, U2.30, U5.6
UART_TX: U1.31, U4.7
UART_TX1: U2.31, U5.7
VBUS: J1.VBUS, RN1.4
VBUSR: C4.1, D2.2, RN1.5, U4.5

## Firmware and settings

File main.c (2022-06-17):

/*
 * main.c
 *
 * Created: 26. 1. 2021.
 * Author : Trax
 */

#include <stdio.h>
#include <avr/io.h>
#include <avr/interrupt.h>
#include <avr/pgmspace.h>
#include <stdlib.h>
#include <avr/eeprom.h>
#include <string.h>
#include <math.h>
#include <util/delay.h>

#include "main.h"

// ticker timer
volatile uint64_t milliseconds = 0;
volatile uint64_t delay_milliseconds = 0;

// ISR led blinked related
volatile uint8_t isr_led_blinker = 0;
volatile uint16_t isr_led_blinker_tmr = 0;
volatile uint16_t isr_led_blinker_rate = ISR_LED_BLINK_NORMAL_MS;

// button related
volatile uint8_t prev_btn = 0; // previous button states for interrupt handling
volatile uint8_t btn_press = 0; // also for the buttons with the isr
volatile uint8_t btn_hold = 0; // also for the buttons with the isr
volatile uint16_t btn_hold_timer = 0; // to detect button holds
volatile uint16_t btn_expect_timer = 0; // to detect idling of button press

volatile uint64_t master_crypt_key = 0; // LOADED FROM EEPROM upon startup

// database tables
volatile struct eedb_ctx eedb_hcsmitm;
volatile struct eedb_ctx eedb_hcsdb;
volatile struct eedb_ctx eedb_hcslogdevices;
volatile struct eedb_ctx eedb_hcsloglogs;
volatile struct eedb_ctx eedb_hcstx;

// misc
volatile uint16_t action_expecter_timer = 0;

// KeeLoq context
volatile struct keeloq_ctx kl_ctx;

// misc working variables
volatile uint8_t option_state; // device options state
volatile uint16_t last_grabbed_eeaddr = EEDB_INVALID_ADDR; // convenient for re-transmitting last collected device :)
volatile uint16_t runtime_grabbed_cnt = 0; // how many new remotes have been collected from previous system (re)start

void foreach_hcs_loglog_record_callback(volatile struct eedb_ctx *ctx, struct eedb_record_header *header, void *record) {
	uart_puts("    foreach_hcs_loglog_record_callback()\r\n");

	struct eedb_log_record *log_record = record;

	uart_puts("    ");
	char tmp[64];
	for(uint8_t i=0; i<KL_BUFF_LEN; i++) {
		sprintf(tmp, "0x%02X ", log_record->kl_rx_buff[i]);
		uart_puts(tmp);
	}
	uart_puts("\r\n");
}

void foreach_hcs_logdevice_record_callback(volatile struct eedb_ctx *ctx, struct eedb_record_header *header, void *record) {
	uart_puts("foreach_hcs_logdevice_record_callback()\r\n");

	struct eedb_hcs_record *hcs_record = record;

	char tmp[64];
	sprintf(tmp, "ENCODER: %u, %lu\r\n", hcs_record->encoder, hcs_record->serial);
	uart_puts(tmp);

	// pokupi child recorde ovog klinca
	struct eedb_log_record one_log_record;
	eedb_for_each_record(&eedb_hcsloglogs, 0, hcs_record->serial, &foreach_hcs_loglog_record_callback, 0, (void *)&one_log_record);

	uart_puts("\r\n");
}

int main(void)
{
	// Misc hardware init
	// this turns off all outputs & leds
	misc_hw_init();

	// UART init
	setInput(DDRD, 0);
	setOutput(DDRD, 1);
	uart_init(calc_UBRR(250000));

	// I2C init
	setInput(DDRC, 4); // SDA data pin input
	setOutput(PORTC, 4); // turn ON internal pullup
	setInput(DDRC, 5); // SCL clock pin input
	setOutput(PORTC, 5); // turn ON internal pullup
	twi_init(calc_TWI(400000)); // Hz

	// Initialize Timer0 overflow ISR for 1ms interval
	TCCR0A = 0;
	TCCR0B = _BV(CS01) | _BV(CS00); // 1:64 prescaled, timer started! at 16MHz this will overflow at 1.024ms
	TIMSK0 |= _BV(TOIE0); // for ISR(TIMER0_OVF_vect)

	// Interrupts ON
	// Note: global interrupts should NOT be disabled, everything is relying on them from now on!
	sei();

	delay_ms_(50);

	// De-init hardware for the KeeLoq programmer... until we use it.
	keeloq_prog_deinit_hw();

	// Setup the context for KeeLoq TX&RX library.
	keeloq_rx_deinit_hw(); // de-init hardware just in case
	kl_ctx.fn_rx_init_hw = &keeloq_rx_init_hw;
	kl_ctx.fn_rx_deinit_hw = &keeloq_rx_deinit_hw;
	kl_ctx.fn_tx_init_hw = &keeloq_init_tx_hw;
	kl_ctx.fn_tx_deinit_hw = &keeloq_deinit_tx_hw;
	kl_ctx.fn_tx_pin_hw = &keeloq_pin_tx_hw;
	// init it
	kl_init_ctx(&kl_ctx);

	#ifdef DEBUG
	char tmp[128];
	#endif

	// read settings from internal EEPROM
	// eeprom has some settings?
    if( eeprom_read_byte((uint8_t *)EEPROM_MAGIC) == EEPROM_MAGIC_VALUE) {
		#ifdef DEBUG
		uart_puts("EEPROM VALID.\r\n");
		#endif

		option_state = eeprom_read_byte((uint8_t *)EEPROM_OPTION_STATES);
		eeprom_read_block((uint64_t *)&master_crypt_key, (uint8_t *)EEPROM_MASTER_CRYPT_KEY, 8);

		// todo: ostalo...
	}
	// nope, use defaults
	else {
		#ifdef DEBUG
		uart_puts("EEPROM INVALID.\r\n");
		#endif

		#warning "PREBACI NA OP_STATE_1 NAKON DEBUGIRANJA TX-a"
		option_state = OP_STATE_4; // only normal receiver enabled by default
		master_crypt_key = 0xB00B1E5B00B1E500; // some random value for development

		// todo: ostalo...

		// prebaci to odma u EEPROM, nastavicemo odatle ubuduce
		update_settings_to_eeprom();
	}

	// initialize EEPROM database tables
	ledb_on();

	// TABLE: HCS101 device identity for the MITM mode
	eedb_hcsmitm.start_eeaddr = 0;
	eedb_hcsmitm.record_capacity = 1;
	eedb_hcsmitm.sizeof_record_entry = sizeof(struct eedb_hcs_record);
	eedb_hcsmitm.i2c_addr = 0b10100000;
	eedb_hcsmitm.fn_i2c_start = &twi_start;
	eedb_hcsmitm.fn_i2c_stop = &twi_stop;
	eedb_hcsmitm.fn_i2c_rx_ack = &twi_rx_ack;
	eedb_hcsmitm.fn_i2c_rx_nack = &twi_rx_nack;
	eedb_hcsmitm.fn_i2c_tx = &twi_tx_byte;
	eedb_init_ctx(&eedb_hcsmitm);
	/*
	#ifdef DEBUG
	sprintf(tmp, "eedb_hcsmitm allocated %u bytes\r\n", eedb_hcsmitm._allocated_bytes_eeaddr);
	uart_puts(tmp);
	#endif
	*/

	// TABLE: HCS device identities
	eedb_hcsdb.start_eeaddr = eedb_hcsmitm._next_free_eeaddr; // start where previous table ended
	eedb_hcsdb.record_capacity = 1000;
	eedb_hcsdb.sizeof_record_entry = sizeof(struct eedb_hcs_record);
	eedb_hcsdb.i2c_addr = 0b10100000;
	eedb_hcsdb.fn_i2c_start = &twi_start;
	eedb_hcsdb.fn_i2c_stop = &twi_stop;
	eedb_hcsdb.fn_i2c_rx_ack = &twi_rx_ack;
	eedb_hcsdb.fn_i2c_rx_nack = &twi_rx_nack;
	eedb_hcsdb.fn_i2c_tx = &twi_tx_byte;
	eedb_init_ctx(&eedb_hcsdb);
	/*
	#ifdef DEBUG
	sprintf(tmp, "eedb_hcsdb allocated %u bytes\r\n", eedb_hcsdb._allocated_bytes_eeaddr);
	uart_puts(tmp);
	#endif
	*/

	// TABLE: HCS sniffing log HCS devices
	eedb_hcslogdevices.start_eeaddr = eedb_hcsdb._next_free_eeaddr; // start where previous table ended
	eedb_hcslogdevices.record_capacity = 500;
	eedb_hcslogdevices.sizeof_record_entry = sizeof(struct eedb_hcs_record);
	eedb_hcslogdevices.i2c_addr = 0b10100000;
	eedb_hcslogdevices.fn_i2c_start = &twi_start;
	eedb_hcslogdevices.fn_i2c_stop = &twi_stop;
	eedb_hcslogdevices.fn_i2c_rx_ack = &twi_rx_ack;
	eedb_hcslogdevices.fn_i2c_rx_nack = &twi_rx_nack;
	eedb_hcslogdevices.fn_i2c_tx = &twi_tx_byte;
	eedb_init_ctx(&eedb_hcslogdevices);
	/*
	#ifdef DEBUG
	sprintf(tmp, "eedb_hcslogdevices allocated %u bytes\r\n", eedb_hcslogdevices._allocated_bytes_eeaddr);
	uart_puts(tmp);
	#endif
	*/

	// TABLE: HCS sniffing log HCS devices LOGs
	// THIS IS A CHILD TABLE OF "eedb_hcslogdevices"
	eedb_hcsloglogs.start_eeaddr = eedb_hcslogdevices._next_free_eeaddr; // start where previous table ended
	eedb_hcsloglogs.record_capacity = 500;
	eedb_hcsloglogs.sizeof_record_entry = sizeof(struct eedb_log_record);
	eedb_hcsloglogs.i2c_addr = 0b10100000;
	eedb_hcsloglogs.fn_i2c_start = &twi_start;
	eedb_hcsloglogs.fn_i2c_stop = &twi_stop;
	eedb_hcsloglogs.fn_i2c_rx_ack = &twi_rx_ack;
	eedb_hcsloglogs.fn_i2c_rx_nack = &twi_rx_nack;
	eedb_hcsloglogs.fn_i2c_tx = &twi_tx_byte;
	eedb_init_ctx(&eedb_hcsloglogs);
	/*
	#ifdef DEBUG
	sprintf(tmp, "eedb_hcsloglogs allocated %u bytes\r\n", eedb_hcsloglogs._allocated_bytes_eeaddr);
	uart_puts(tmp);
	#endif
	*/

	// TABLE: HCS transmitter/tx emulator device
	eedb_hcstx.start_eeaddr = eedb_hcsloglogs._next_free_eeaddr; // start where previous table ended
	eedb_hcstx.record_capacity = 1;
	eedb_hcstx.sizeof_record_entry = sizeof(struct eedb_hcs_record);
	eedb_hcstx.i2c_addr = 0b10100000;
	eedb_hcstx.fn_i2c_start = &twi_start;
	eedb_hcstx.fn_i2c_stop = &twi_stop;
	eedb_hcstx.fn_i2c_rx_ack = &twi_rx_ack;
	eedb_hcstx.fn_i2c_rx_nack = &twi_rx_nack;
	eedb_hcstx.fn_i2c_tx = &twi_tx_byte;
	eedb_init_ctx(&eedb_hcstx);
	/*
	#ifdef DEBUG
	sprintf(tmp, "eedb_hcstx allocated %u bytes\r\n", eedb_hcstx._allocated_bytes_eeaddr);
	uart_puts(tmp);
	#endif
	*/

	ledb_off();

	// changing option states on startup?
	// check to see if button S0 is pressed upon startup
	uint8_t was_setup = 0;
	if( !(BTNS0_PINREG & _BV(BTNS0_PIN)) ) {
		leda_on();

		delay_ms_(500);

		was_setup = 1;

		uint8_t option_state_new = option_state;
		uint8_t option_index = 1;

		clear_pending_buttons(); // clear any pending button press or hold
		btn_expect_timer = BTN_MODE_CHANGE_EXPECTER;
		milliseconds = BTN_MODE_CHANGE_CURR_REPORTER; // report state now! - use ticker to periodically report current mode of operation
		while(btn_expect_timer) {

			// button S1 selects the option
			if(btn_press & BTNS1_MASK) {
				btn_press &= ~BTNS1_MASK; // clear press
				btn_expect_timer = BTN_MODE_CHANGE_EXPECTER; // reload

				option_index++;
				if(option_index > OP_STATE_LEN) {
					option_index = 1;
				}

				milliseconds = BTN_MODE_CHANGE_CURR_REPORTER; // report state now!
			}

			// button S2 changes currently selected option's state
			if(btn_press & BTNS2_MASK) {
				btn_press &= ~BTNS2_MASK; // clear press
				btn_expect_timer = BTN_MODE_CHANGE_EXPECTER; // reload

				option_state_new ^= _BV(option_index - 1); // toggle

				milliseconds = BTN_MODE_CHANGE_CURR_REPORTER; // report state now!
			}

			// periodically report currently selected option's state on LED C
			if (milliseconds >= BTN_MODE_CHANGE_CURR_REPORTER) {
				// report current option
				ledb_blink(option_index);

				// report this option's state
				ledc_blink(1 + !!(option_state_new & _BV(option_index - 1)));

				milliseconds = 0;
			}

			// terminate setup?
			// button S3 terminates the process of setup, not to wait for the timeout
			if(btn_press & BTNS3_MASK) {
				btn_press &= ~BTNS3_MASK; // clear press
				btn_expect_timer = 0; // this should do it
			}
		}

		// op-mode changed?
		if(option_state_new != option_state)
		{
			option_state = option_state_new;

			// addon:
			// if all options are disabled: enable option 1
			if(option_state == 0) option_state = OP_STATE_1;
			// if option 4 is enabled: disable all other options
			if(option_state & OP_STATE_4) option_state = OP_STATE_4;

			// save new mode to eeprom
			update_settings_to_eeprom();
		}

		leda_off();
	}

	// DEBUGGING: print all collected hcs devices
	#ifdef DEBUG
	if(option_state & OP_STATE_3) {
		struct eedb_hcs_record one_record;
		eedb_for_each_record(&eedb_hcslogdevices, EEDB_PKFK_ANY, 0, &foreach_hcs_logdevice_record_callback, 0, (void *)&one_record);
	}
	#endif

	// report state of all options on LED A
	if(!was_setup) {
		if (option_state & OP_STATE_1) { leda_blink(1); delay_ms_(450); }
		if (option_state & OP_STATE_2) { leda_blink(2); delay_ms_(450); }
		if (option_state & OP_STATE_3) { leda_blink(3); delay_ms_(450); }
		if (option_state & OP_STATE_4) { leda_blink(4); delay_ms_(450); }
	}
	ledc_blink(1);

	#ifdef DEBUG
	uart_puts("Option 1: ");
	if (option_state & OP_STATE_1) uart_puts("ON.\r\n");
	else uart_puts("OFF.\r\n");
	uart_puts("Option 2: ");
	if (option_state & OP_STATE_2) uart_puts("ON.\r\n");
	else uart_puts("OFF.\r\n");
	uart_puts("Option 3: ");
	if (option_state & OP_STATE_3) uart_puts("ON.\r\n");
	else uart_puts("OFF.\r\n");
	uart_puts("Option 4: ");
	if (option_state & OP_STATE_4) uart_puts("ON.\r\n");
	else uart_puts("OFF.\r\n");
	sprintf(tmp, "CRYPT KEY: 0x%04X%04X%04X%04X\r\n", (uint16_t)(master_crypt_key >> 48), (uint16_t)(master_crypt_key >> 32), (uint16_t)(master_crypt_key >> 16), (uint16_t)master_crypt_key);
	uart_puts(tmp);
	#endif

	uart_puts("RESUME>\r\nEND>\r\n");

	/*
	1.	Option 1: Receiver module with memory of up to 1000 remote transmitters
	2.	Option 2: MITM upgrader for upgrading third-party systems (insecure garage door openers)
	3.	Option 3: Data collector with memory of up to 200 remote transmitters and 500 transmissions
	*/
	if(!(option_state & OP_STATE_4)) {
		// start KeeLoq decoder as clearly we are not in remote transmitter emulator
		kl_rx_stop(&kl_ctx);
		kl_rx_start(&kl_ctx); // start the keeloq rx

		// for looping and processing
		uint8_t processed = 0;
		uint8_t decode_ok = 0;
		uint8_t record_found = 0;
		struct KEELOQ_DECODE_PLAIN decoded;
		// for options 1 & 2
		struct eedb_record_header header;
		struct eedb_hcs_record record;
		clear_pending_buttons(); // clear any pending button press or hold
		while(1)
		{
			// check buttons for various commands
			// but only if we are not currently receiving anything
			if (kl_ctx.kl_rx_rf_act == KL_RF_ACT_IDLE) {
				uint8_t need_to_reinit_kl_rx = handle_ui_buttons();
				// re-start KeeLoq decoder because there was some programming done and hardware *might need* to be re-initialized
				if(need_to_reinit_kl_rx) {
					kl_rx_stop(&kl_ctx);
					kl_rx_start(&kl_ctx); // start the keeloq rx
				}
			}

			// turn LED A on while button is being pressed on a remote
			if(kl_ctx.kl_rx_rf_act == KL_RF_ACT_BUSY) {
				leda_on();
			}

			// KeeLoq library received something
			if (kl_ctx.kl_rx_buff_state == KL_BUFF_FULL) {
				// perform processing, just once
				if (!processed) {
					processed = 1;

					#ifdef DEBUG
					uart_puts("RX!\r\n");
					#endif

					memset(&decoded, 0, sizeof(struct KEELOQ_DECODE_PLAIN));
					memset(&header, 0, sizeof(struct eedb_record_header));
					memset(&record, 0, sizeof(struct eedb_hcs_record));
					record_found = 0;

					decode_ok = keeloq_decode((uint8_t *)kl_ctx.kl_rx_buff, kl_ctx.kl_rx_buff_bit_index, 0, &decoded);
					// decoding is OK?
					if (decode_ok) {
						#ifdef DEBUG
						sprintf(tmp, "SERIAL: %lu\r\n", decoded.serial);
						uart_puts(tmp);
						#endif

						record_found = event_keydown(&decoded, &header, &record, (uint8_t *)kl_ctx.kl_rx_buff);
					}
				}
				/*
				// each other time if it is still pressed, call it again but with a flag
				else if (processed) {
					// decoding & verified was OK? just PROCESS it immediatelly
					if (decode_ok && verify_ok) {
						event_keydown(&decoded, &header, &record, (uint8_t *)kl_ctx.kl_rx_buff, 1);
					}
				}
				*/
			}

			// transmission processed, and finally has ended (i.e. button released on the remote)
			if (kl_ctx.kl_rx_rf_act == KL_RF_ACT_IDLE) {
				leda_off();

				// if it was processed, it is safe to call keyup event
				if(processed) {
					kl_rx_flush(&kl_ctx); // "flush" buffer, make room for next code to be pushed into the RX buffer

					#ifdef DEBUG
					uart_puts("RX STOP.\r\n\r\n");
					#endif

					// decoding was OK?
					if (decode_ok && record_found) {
						event_keyup(&decoded, &header, &record);
					}

					record_found = 0;
					processed = 0;
				}
			}
		} // end while
	} // end if
	/*
	4.	Option 4: Transmitter emulator
	*/
	else {
		// when in tx emulation mode, buttons are used for starting rf transmittion
		// we use raw buttons here, without debouncer. we will later see if it is a smart thing to do or not...
		PCICR &= ~_BV(BTNS0_PCICRBIT); // disable button ISRs
		PCICR &= ~_BV(BTNS1_PCICRBIT); // disable button ISRs
		PCICR &= ~_BV(BTNS2_PCICRBIT); // disable button ISRs
		PCICR &= ~_BV(BTNS3_PCICRBIT); // disable button ISRs
		uint8_t prev_buttons = 0xFF;
		struct eedb_hcs_record tx_emulator_record;

		// DEBUG - SAVE A TEST PROFILE TO DB
		tx_emulator_record.encoder = ENCODER_HCS101;
		tx_emulator_record.buttons = 0;
		tx_emulator_record.counter = 5175;
		tx_emulator_record.crypt_key = 0;
		tx_emulator_record.discrimination = 0;
		tx_emulator_record.header_length = 2800;
		tx_emulator_record.timing_element = 390;
		tx_emulator_record.serial = 92071127;
		tx_emulator_record.serial3 = 0;
		//eedb_format_memory(&eedb_hcstx);
		eedb_insert_record(&eedb_hcstx, tx_emulator_record.serial, 0, &tx_emulator_record);
		// - DEBUG

		char tx_emulator_kl_buff[KL_BUFF_LEN];
		uint16_t tx_emulator_eeaddr = EEDB_INVALID_ADDR;
		while (1) {
			uint8_t buttons = 0;
			if( !(BTNS0_PINREG & _BV(BTNS0_PIN)) ) {
				buttons |= 0b00000010;
			}
			if( !(BTNS1_PINREG & _BV(BTNS1_PIN)) ) {
				buttons |= 0b00000100;
			}
			if( !(BTNS2_PINREG & _BV(BTNS2_PIN)) ) {
				buttons |= 0b00001000;
			}
			if( !(BTNS3_PINREG & _BV(BTNS3_PIN)) ) {
				buttons |= 0b00000001;
			}

			// something to transmit?
			if(buttons) {
				// re-start transmission (also initial transmission is here)
				// additional button pressed/released DURING current transmission?
				if(prev_buttons != buttons) {
					prev_buttons = buttons;

					// prepare the transmission word
					tx_emulator_eeaddr = eedb_find_record_eeaddr(&eedb_hcstx, EEDB_PKFK_ANY, 0, 0);
					if (tx_emulator_eeaddr != EEDB_INVALID_ADDR) {
						ledb_on();

						eedb_read_record_by_eeaddr(&eedb_hcstx, tx_emulator_eeaddr, 0, &tx_emulator_record);

						struct KEELOQ_DECODE_PLAIN tx_emulator_decoded;
						tx_emulator_decoded.buttons = buttons;
						tx_emulator_decoded.counter = ++tx_emulator_record.counter; // increment counter value in the record
						tx_emulator_decoded.serial = tx_emulator_record.serial; // yo!
						tx_emulator_decoded.serial3 = tx_emulator_record.serial3;
						tx_emulator_decoded.discrimination = tx_emulator_record.discrimination;
						tx_emulator_decoded.repeat = 0; // make me sometimes in the future...
						tx_emulator_decoded.vlow = 0;

						// update tx profile, the counter value has changed above (++tx_emulator_record.counter)
						eedb_update_record(&eedb_hcstx, EEDB_PKFK_ANY, 0, 0, 0, &tx_emulator_record);

						// encode
						keeloq_encode(tx_emulator_record.encoder, &tx_emulator_decoded, tx_emulator_record.crypt_key, (uint8_t *)&tx_emulator_kl_buff);

						#ifdef DEBUG
						uart_puts("TX: ");
						for(uint8_t i=0; i<KL_BUFF_LEN; i++) {
							sprintf(tmp, "0x%02X ", tx_emulator_kl_buff[i]);
							uart_puts(tmp);
						}
						uart_puts("\r\n");
						#endif

						ledb_off();
					}
				}

				// transmit if there is TX profile in memory
				if(tx_emulator_eeaddr != EEDB_INVALID_ADDR) {
					ledc_on();
					kl_tx(&kl_ctx, (uint8_t *)&tx_emulator_kl_buff, 66, tx_emulator_record.timing_element, 12, tx_emulator_record.header_length, 13500);
					ledc_off();
				}
				// report error
				else {
					leda_blink(3);
					delay_builtin_ms_(500);
				}
			}
			else {
				prev_buttons = 0xFF;
			}
		} // end while
	} // end if
}
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

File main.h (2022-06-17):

/*
 * main.h
 *
 * Created: 26. 1. 2021. 09:56:45
 *  Author: Trax
 */

#ifndef MAIN_H_
#define MAIN_H_

#include "lib/uart/uart.h"
#include "lib/i2c/i2c.h"

#include "keeloq.h"
#include "keeloq_decode.h"
#include "keeloq_prog.h"
#include "ee_db.h"
#include "ee_db_record.h"

#define DEBUG 1

// Limitations: ATmega328P (and family) PORTB.4 can only be used as INPUT if SPI mode is enabled.

#ifndef F_CPU
	#error You must define CPU frequency (F_CPU) in AVR Studio (Project Properties -> Toolchain -> Symbols >> add F_CPU=16000000UL) or your Makefile
#endif

#ifndef _BV
	#define _BV(n) (1 << n)
#endif

#define	calc_UBRR(bau)			(F_CPU/16/bau-1)
#define calc_TWI(khz)			(((F_CPU/khz) - 16)/2)

#define nop() asm volatile("nop")

// EEPROM addresses
#define	EEPROM_START				(0)								// start of our data in eeprom is here
#define EEPROM_MAGIC				(EEPROM_START + 0)				// eeprom OK - magic value
#define EEPROM_OPTION_STATES		(EEPROM_MAGIC + 1)				// state of operating options
#define EEPROM_MASTER_CRYPT_KEY		(EEPROM_OPTION_STATES + 1)		// master crypt key for learning encrypted HCS devices via RF

#define EEPROM_MAGIC_VALUE			0xAA

// Device options state
#define OP_STATE_1		0b00000001	// Receiver module
#define OP_STATE_2		0b00000010	// MITM upgrader
#define OP_STATE_3		0b00000100	// Grab, collect
#define OP_STATE_4		0b00001000	// Remote emulator from memory
#define OP_STATE_LEN	4			// 4 options currently implemented

// RF IN data pin
#define	RX_PIN			2
#define	RX_DDR			DDRB
#define	RX_PINREG		PINB
#define	RX_PORT			PORTB
#define	RX_PCINTBIT		PCINT2
#define	RX_PCMSKREG		PCMSK0
#define	RX_PCICRBIT		PCIE0

// RF OUT data pin PORTB.1 (OC1A pin is data output)
#define	TX_PIN			1
#define	TX_DDR			DDRB
#define	TX_PORT			PORTB

// OPTOCOUPLERs outputs S0..S3
#define	S0_PIN			2
#define	S0_DDR			DDRC
#define	S0_PORT			PORTC

#define	S1_PIN			3
#define	S1_DDR			DDRC
#define	S1_PORT			PORTC

#define	S2_PIN			1
#define	S2_DDR			DDRC
#define	S2_PORT			PORTC

#define	S3_PIN			0
#define	S3_DDR			DDRC
#define	S3_PORT			PORTC

// BUTTONs inputs
#define	BTNS0_PIN			2
#define	BTNS0_DDR			DDRD
#define	BTNS0_PINREG		PIND
#define	BTNS0_PORT			PORTD
#define	BTNS0_PCINTBIT		PCINT18
#define	BTNS0_PCMSKREG		PCMSK2
#define	BTNS0_PCICRBIT		PCIE2

#define	BTNS1_PIN			3
#define	BTNS1_DDR			DDRD
#define	BTNS1_PINREG		PIND
#define	BTNS1_PORT			PORTD
#define	BTNS1_PCINTBIT		PCINT19
#define	BTNS1_PCMSKREG		PCMSK2
#define	BTNS1_PCICRBIT		PCIE2

#define	BTNS2_PIN			4
#define	BTNS2_DDR			DDRD
#define	BTNS2_PINREG		PIND
#define	BTNS2_PORT			PORTD
#define	BTNS2_PCINTBIT		PCINT20
#define	BTNS2_PCMSKREG		PCMSK2
#define	BTNS2_PCICRBIT		PCIE2

#define	BTNS3_PIN			5
#define	BTNS3_DDR			DDRD
#define	BTNS3_PINREG		PIND
#define	BTNS3_PORT			PORTD
#define	BTNS3_PCINTBIT		PCINT21
#define	BTNS3_PCMSKREG		PCMSK2
#define	BTNS3_PCICRBIT		PCIE2

// for prev_btn & btn_hold global variables
#define BTNS0_MASK			0b00000001
#define BTNS1_MASK			0b00000010
#define BTNS2_MASK			0b00000100
#define BTNS3_MASK			0b00001000

// Button related timers
#define	BTN_HOLD_TMR						950		// miliseconds to pronounce button as held rather than pressed
#define BTN_MODE_CHANGE_EXPECTER			15000	// ms to exit the mode-change.. mode
#define BTN_MODE_CHANGE_CURR_REPORTER		2000	// ms, on every this much report current mode of operation
#define BTN_PROG_N_ENROLL_EXPECTER			20000	// ms to expect button press for programming the encoder IC
#define BTN_REMOVE_REMOTE_EXPECTER			10000	// ms to expect remote reception via RF and to remove it
#define BTN_ENROLL_FIRST_REMOTE_EXPECTER	10000	// ms to expect FIRST remote reception via RF and to enroll it
#define BTN_ENROLL_SECOND_REMOTE_EXPECTER	5000	// ms to expect SECOND remote reception via RF and to enroll it
#define BTN_CLEAR_MEMORY_EXPECTER			5000	// ms to expect second button hold for entire memory to be cleared

// LEDs
#define	LEDA_PIN		0
#define	LEDA_DDR		DDRB
#define	LEDA_PORT		PORTB

#define	LEDB_PIN		7
#define	LEDB_DDR		DDRD
#define	LEDB_PORT		PORTD

#define	LEDC_PIN		6
#define	LEDC_DDR		DDRD
#define	LEDC_PORT		PORTD

// HCS PROGRAMMER PINS
// DATA
#define	HCS_PROG_DATA_PIN		3
#define	HCS_PROG_DATA_DDR		DDRB
#define	HCS_PROG_DATA_PINREG	PINB
#define	HCS_PROG_DATA_PORT		PORTB
// S0&S1 pins
#define	HCS_PROG_S0S1_PIN		4
#define	HCS_PROG_S0S1_DDR		DDRB
#define	HCS_PROG_S0S1_PINREG	PINB
#define	HCS_PROG_S0S1_PORT		PORTB
// S2/CLK pin
#define	HCS_PROG_S2CLK_PIN		5
#define	HCS_PROG_S2CLK_DDR		DDRB
#define	HCS_PROG_S2CLK_PINREG	PINB
#define	HCS_PROG_S2CLK_PORT		PORTB
// S3 pin
#define	HCS_PROG_S3_PIN			1
#define	HCS_PROG_S3_DDR			DDRB
#define	HCS_PROG_S3_PINREG		PINB
#define	HCS_PROG_S3_PORT		PORTB

// Code macros
#define setInput(ddr, pin)		( (ddr) &= (uint8_t)~_BV(pin) )
#define setOutput(ddr, pin)		( (ddr) |= (uint8_t)_BV(pin) )

#define set0(port, pin)			( (port) &= (uint8_t)~_BV(pin) )
#define setLow(port, pin)		( (port) &= (uint8_t)~_BV(pin) )
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

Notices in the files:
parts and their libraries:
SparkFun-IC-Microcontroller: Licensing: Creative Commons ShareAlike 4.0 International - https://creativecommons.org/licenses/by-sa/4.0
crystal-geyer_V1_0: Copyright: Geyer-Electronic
